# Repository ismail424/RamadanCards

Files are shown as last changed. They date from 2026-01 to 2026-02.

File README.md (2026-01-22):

# Digital Ramadan Cards Project

**By Ismail Sacic**

Welcome to the Digital Ramadan Cards project! This repository contains the design and source files for creating unique, digital printed circuit board (PCB) cards specifically designed for Ramadan.

## Project Overview

I am creating digital Ramadan cards that combine traditional aesthetics with modern electronics. These cards are designed using KiCad and can be manufactured as PCBs. They serve as beautiful, tech-inspired gifts or decorative pieces to celebrate the holy month of Ramadan.

### Features
- **Design Year**: 2026
- **Format**: KiCad PCB Design
- **Custom Graphics**: Includes custom silk screen art (Mosque/Stars).

## Preview

Here are some preview images of the 2026 card design:

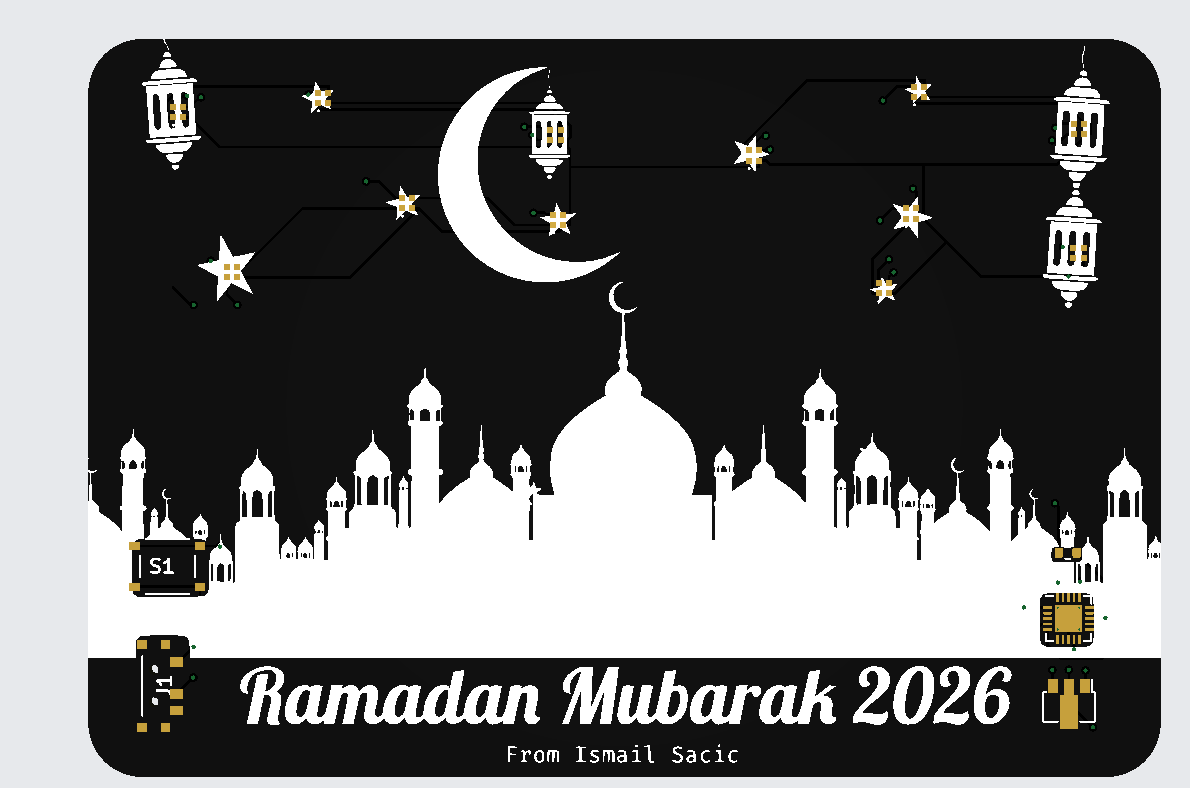
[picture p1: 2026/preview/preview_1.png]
Card Preview 1

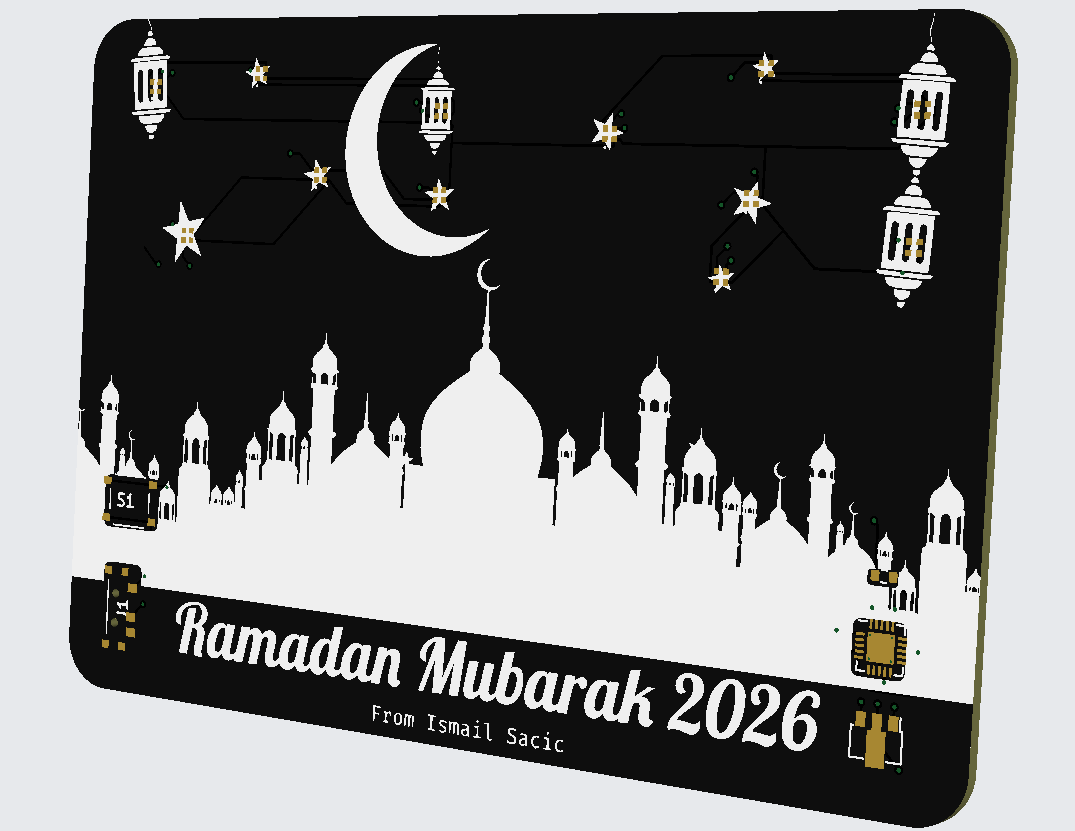
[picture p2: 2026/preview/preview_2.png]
Card Preview 2

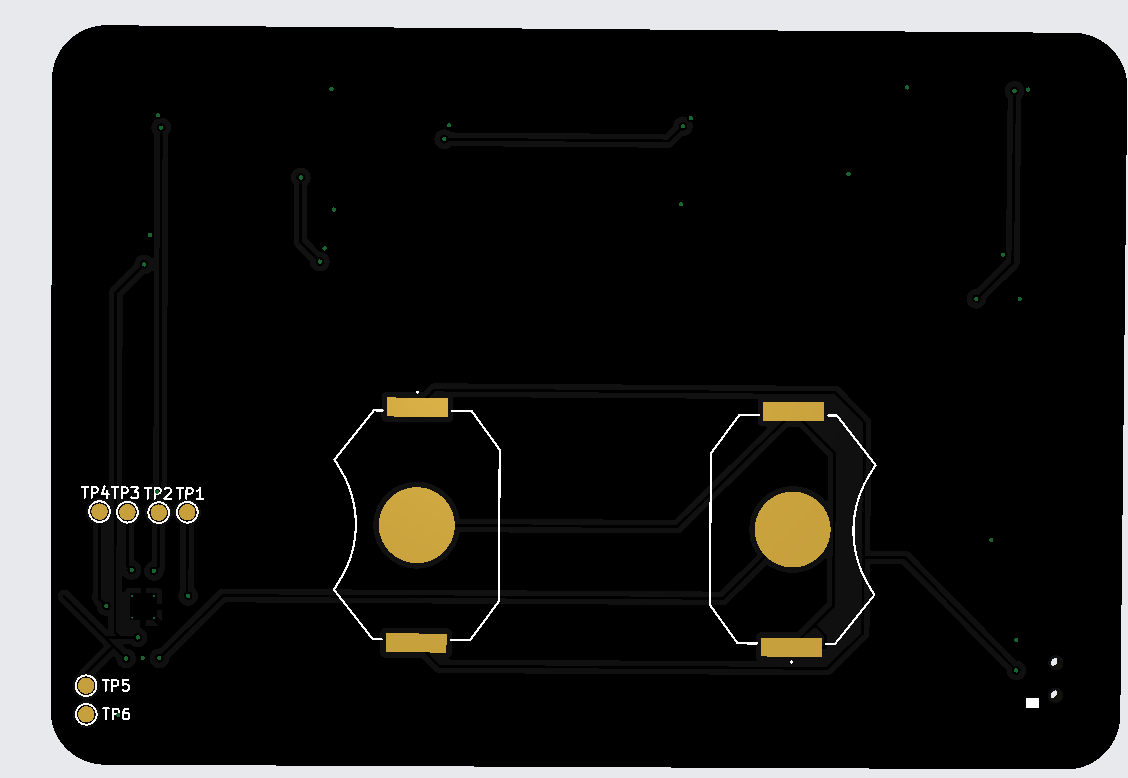
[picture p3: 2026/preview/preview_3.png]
Card Preview 3


## Repository Structure

- `2026/` : Contains the KiCad project files for the 2026 edition.
  - `gr/` : Gerber files for manufacturing.
  - `Graphics/` : Custom footprints and graphics used on the PCB.
  - `preview/` : Images of the design.

## How to Open

1. Install [KiCad](https://www.kicad.org/).
2. Open the `.kicad_pro` file located in the `2026/` directory.

## License

**Copyright © 2026 Ismail Sacic. All Rights Reserved.**

This project is for personal viewing only. **You are not allowed to manufacture, produce, or sell** cards based on this design. See the [LICENSE](LICENSE) file for more details.

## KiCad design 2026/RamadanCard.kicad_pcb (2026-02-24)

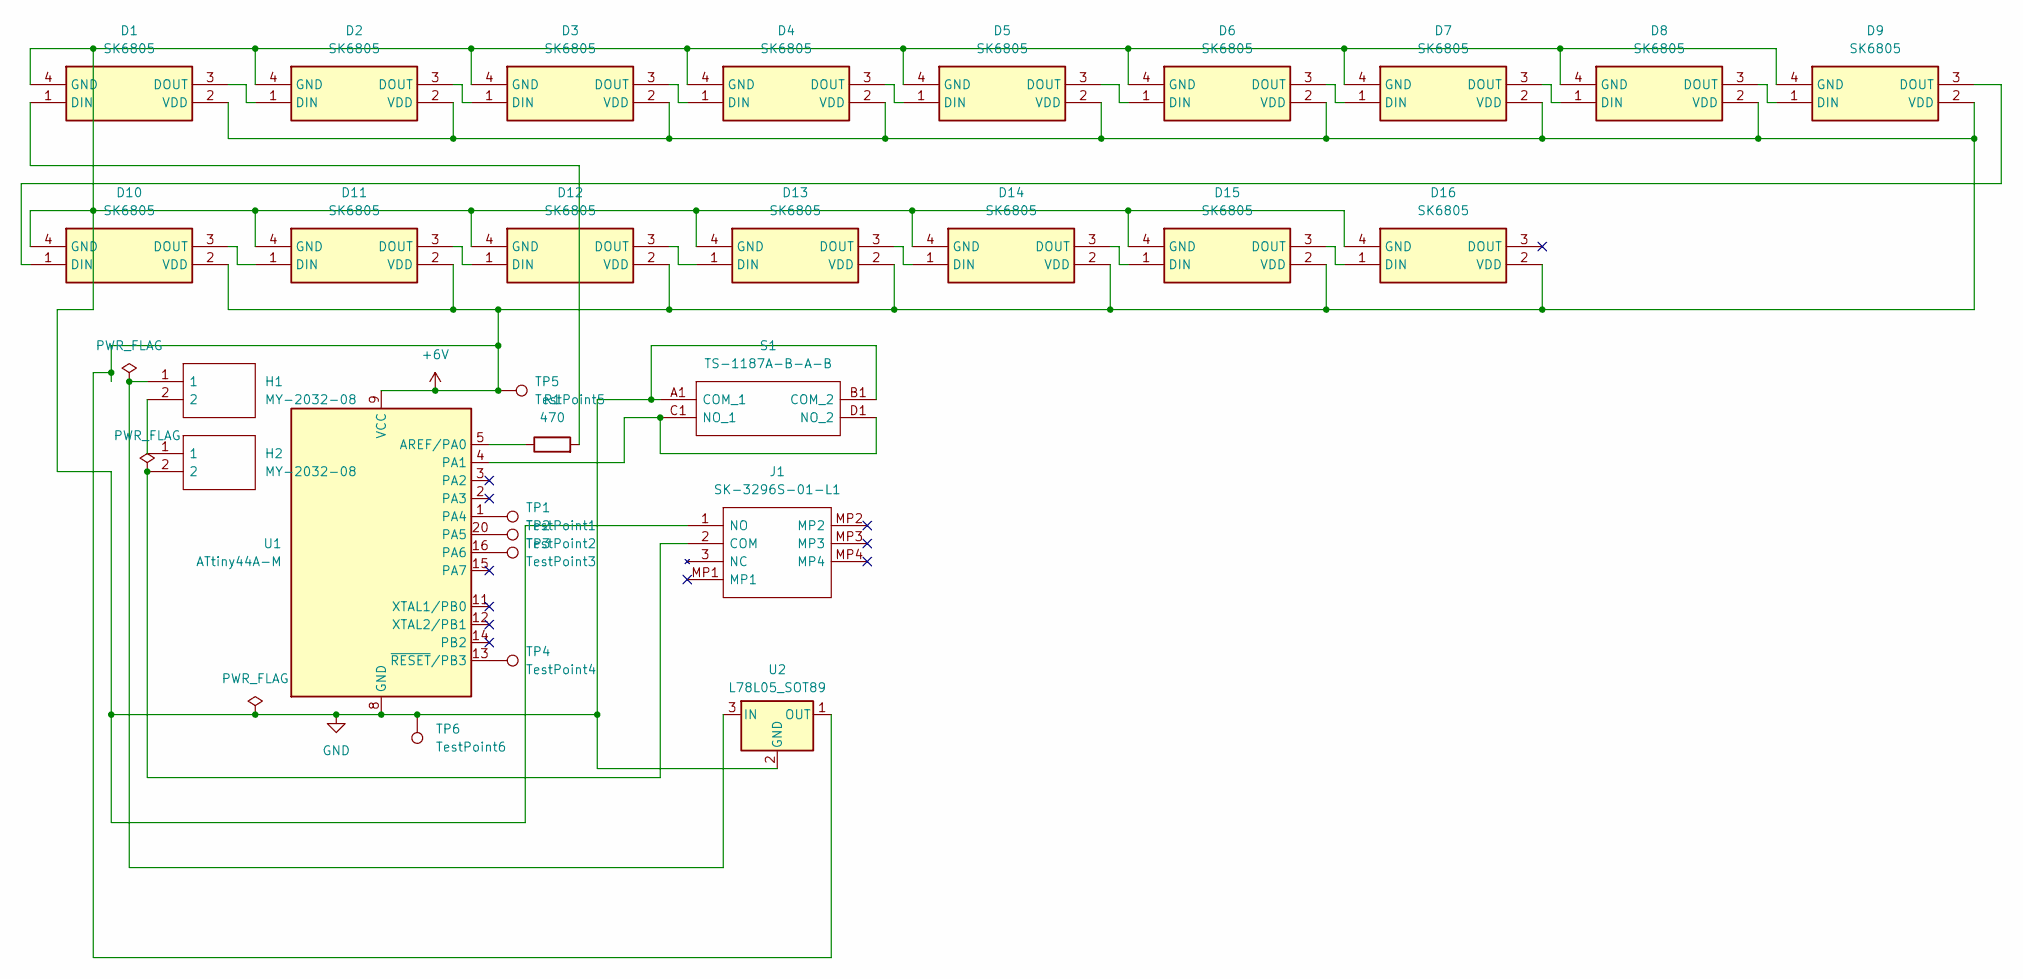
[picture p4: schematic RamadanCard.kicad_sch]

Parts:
D1, D2, D3, D4, D5, D6, D7, D8, D9, D10, D11, D12, D13, D14, D15, D16: SK6805; LED_SK6812_EC15_1.5x1.5mm; Manufacturer_Part_Number SK6805-EC15
H1, H2: MY-2032-08; MY203208; Manufacturer_Part_Number MY-2032-08
J1: SK-3296S-01-L1; SK3296S01L1; Manufacturer_Part_Number SK-3296S-01-L1
R1: 470; R_0603_1608Metric
S1: TS-1187A-B-A-B; TS1187ABAB; Manufacturer_Part_Number TS-1187A-B-A-B
TP1: TestPoint1; TestPoint_Pad_D1.5mm
TP2: TestPoint2; TestPoint_Pad_D1.5mm
TP3: TestPoint3; TestPoint_Pad_D1.5mm
TP4: TestPoint4; TestPoint_Pad_D1.5mm
TP5: TestPoint5; TestPoint_Pad_D1.5mm
TP6: TestPoint6; TestPoint_Pad_D1.5mm
U1: ATtiny44A-M; QFN-20-1EP_4x4mm_P0.5mm_EP2.5x2.5mm_ThermalVias
U2: L78L05_SOT89; SOT-89-3

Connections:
+6V: D1.2 (VDD), D2.2 (VDD), D3.2 (VDD), D4.2 (VDD), D5.2 (VDD), D6.2 (VDD), D7.2 (VDD), D8.2 (VDD), D9.2 (VDD), D10.2 (VDD), D11.2 (VDD), D12.2 (VDD), D13.2 (VDD), D14.2 (VDD), D15.2 (VDD), D16.2 (VDD), TP5.1, U1.9 (VCC), U2.1 (OUT)
GND: D1.4 (GND), D2.4 (GND), D3.4 (GND), D4.4 (GND), D5.4 (GND), D6.4 (GND), D7.4 (GND), D8.4 (GND), D9.4 (GND), D10.4 (GND), D11.4 (GND), D12.4 (GND), D13.4 (GND), D14.4 (GND), D15.4 (GND), D16.4 (GND), J1.1 (NO), S1.A1 (COM_1), S1.B1 (COM_2), TP6.1, U1.8 (GND), U1.21 (GND), U2.2 (GND)
unnamed: D1.1 (DIN), R1.2
unnamed: D1.3 (DOUT), D2.1 (DIN)
unnamed: D2.3 (DOUT), D3.1 (DIN)
unnamed: D3.3 (DOUT), D4.1 (DIN)
unnamed: D4.3 (DOUT), D5.1 (DIN)
unnamed: D5.3 (DOUT), D6.1 (DIN)
unnamed: D6.3 (DOUT), D7.1 (DIN)
unnamed: D7.3 (DOUT), D8.1 (DIN)
unnamed: D8.3 (DOUT), D9.1 (DIN)
unnamed: D9.3 (DOUT), D10.1 (DIN)
unnamed: D10.3 (DOUT), D11.1 (DIN)
unnamed: D11.3 (DOUT), D12.1 (DIN)
unnamed: D12.3 (DOUT), D13.1 (DIN)
unnamed: D13.3 (DOUT), D14.1 (DIN)
unnamed: D14.3 (DOUT), D15.1 (DIN)
unnamed: D15.3 (DOUT), D16.1 (DIN)
unnamed: H1.2, H2.1
unnamed: H2.2, J1.2 (COM)
unnamed: S1.C1 (NO_1), S1.D1 (NO_2), U1.4 (PA1)
unnamed: R1.1, U1.5 (AREF/PA0)
unnamed: TP1.1, U1.1 (PA4)
unnamed: TP2.1, U1.20 (PA5)
unnamed: TP3.1, U1.16 (PA6)
unnamed: TP4.1, U1.13 (~RESET/PB3)
unnamed: H1.1, U2.3 (IN)

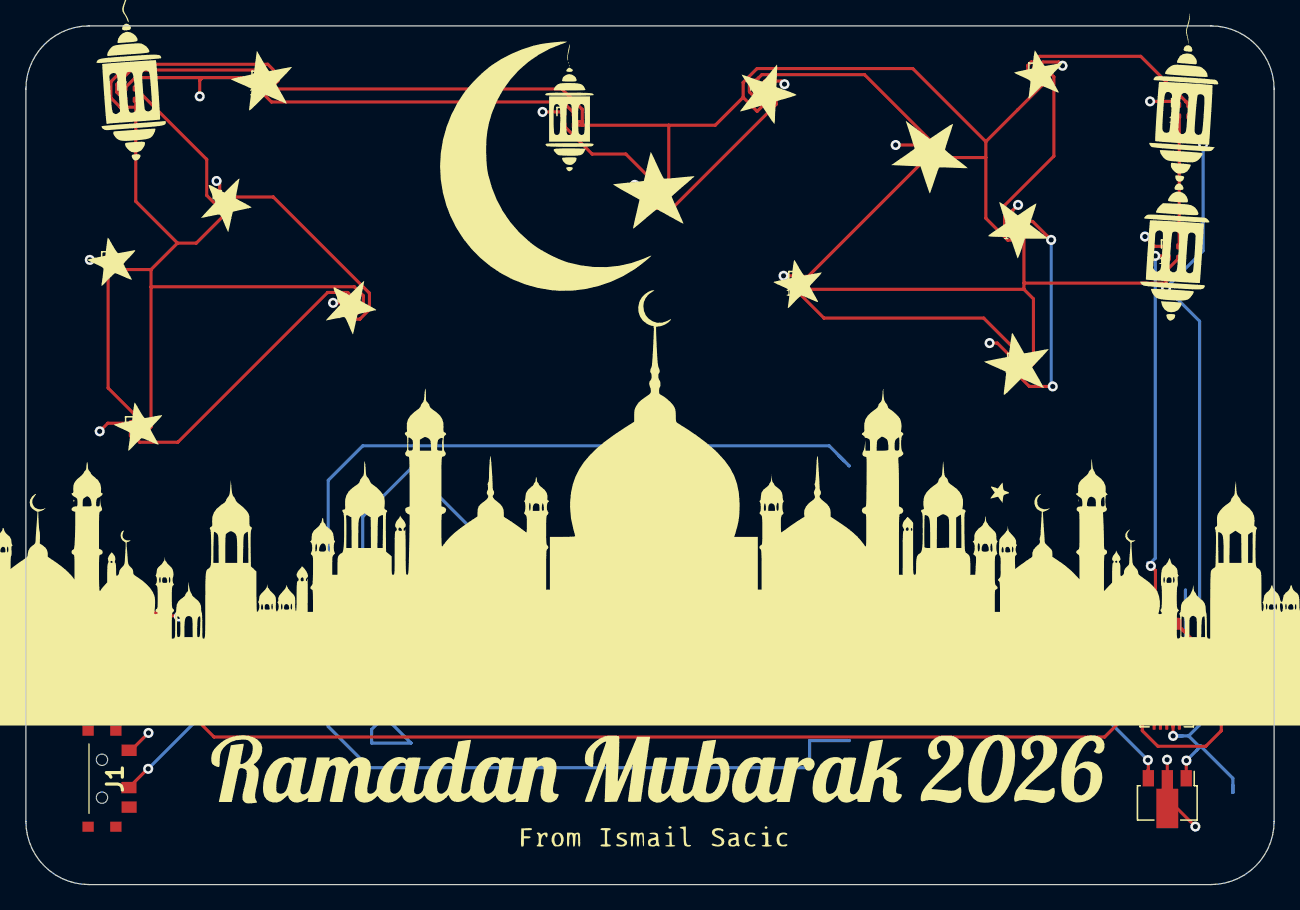
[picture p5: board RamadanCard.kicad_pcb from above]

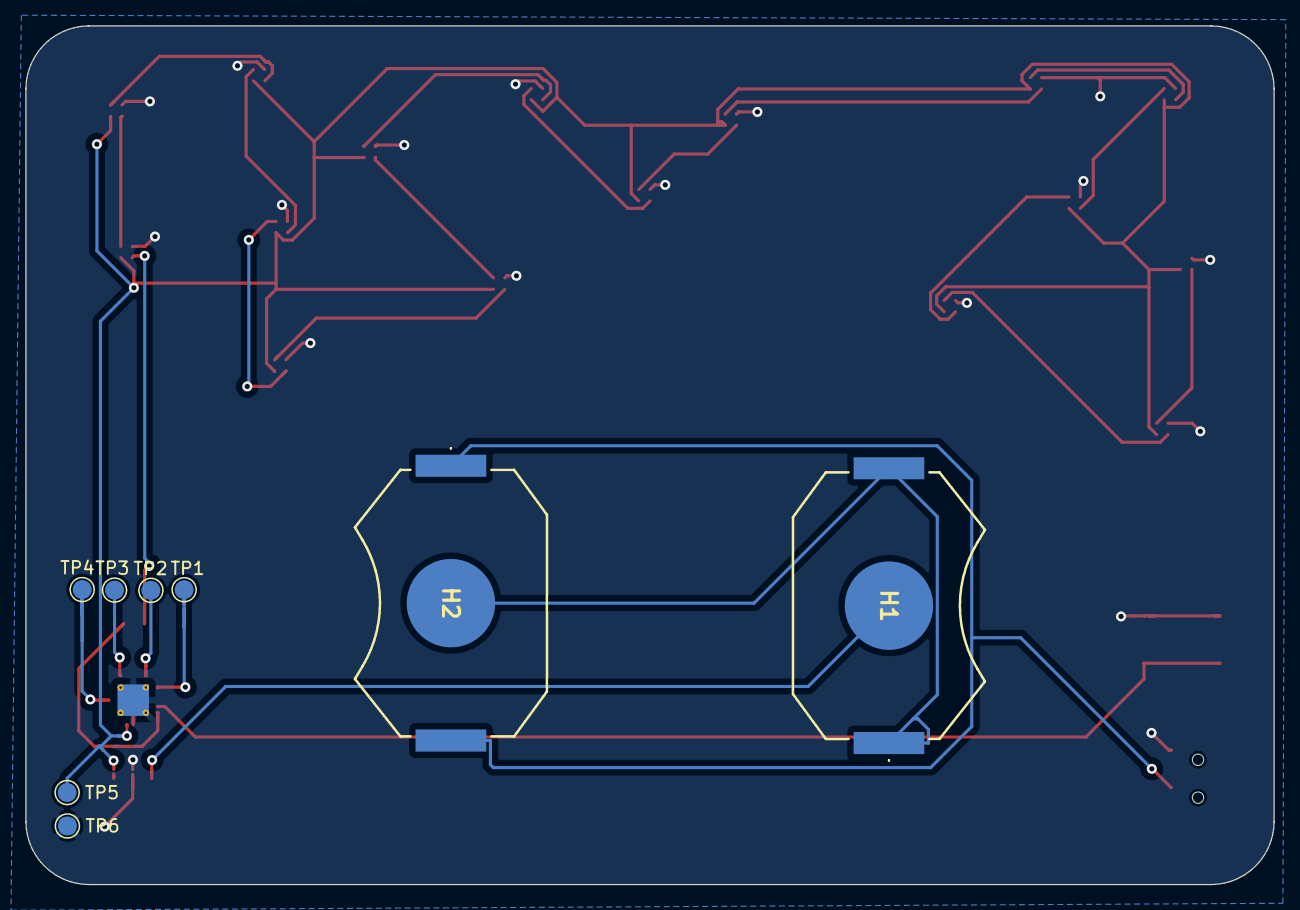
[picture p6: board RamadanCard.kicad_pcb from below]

Board: 2 copper layers, 98.8 x 68.0 mm, 29 parts (8 on the bottom side), 27 nets.

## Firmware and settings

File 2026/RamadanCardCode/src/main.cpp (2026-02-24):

#include <Arduino.h>
#include <FastLED.h>

#define LED_PIN     0
#define COLOR_ORDER GRB
#define CHIPSET     WS2812B
#define NUM_LEDS    16
#define BRIGHTNESS  100
#define BUTTON_PIN  9
#define HOLD_MS     400
#define CLICK_GAP   350

CRGB leds[NUM_LEDS];

uint8_t mode = 0;
uint8_t clickCount = 0;
bool lastBtn = false;
bool holding = false;
unsigned long pressTime = 0;
unsigned long releaseTime = 0;
uint8_t seq0 = 0, seq1 = 0, seq2 = 0;

void twinkle() {
  fadeToBlackBy(leds, NUM_LEDS, 20);
  if (random8() < 80)
    leds[random8(NUM_LEDS)] = CRGB(255, 180, 50);
}

void breathe() {
  uint8_t t = millis() >> 3;
  uint8_t v = (t < 128) ? t * 2 : (255 - t) * 2;
  fill_solid(leds, NUM_LEDS, CRGB(v, v >> 1, 0));
}

void rainbow() {
  fill_rainbow(leds, NUM_LEDS, millis() / 20, 28);
}

// 424 easter egg: lights up 4, 2, 4 stars one by one
void show424() {
  fill_solid(leds, NUM_LEDS, CRGB::Black);
  uint8_t p = 0;
  for (uint8_t d = 0; d < 3; d++) {
    for (uint8_t i = 0; i < ((d == 1) ? 2 : 4); i++) {
      leds[p++] = CRGB(255, 180, 50);
      FastLED.show(); delay(200);
    }
    delay(500);
  }
}

void setup() {
  delay(500);
  pinMode(BUTTON_PIN, INPUT_PULLUP);
  FastLED.addLeds<CHIPSET, LED_PIN, COLOR_ORDER>(leds, NUM_LEDS);
  FastLED.setBrightness(BRIGHTNESS);
}

void loop() {
  bool btn = (digitalRead(BUTTON_PIN) == LOW);
  unsigned long now = millis();

  if (btn && !lastBtn) { pressTime = now; holding = false; }
  if (btn && !holding && (now - pressTime > HOLD_MS)) { holding = true; clickCount = 0; }
  if (!btn && lastBtn) {
    if (!holding) { clickCount++; releaseTime = now; }
    holding = false;
  }
  if (clickCount > 0 && !btn && (now - releaseTime > CLICK_GAP)) {
    seq0 = seq1; seq1 = seq2; seq2 = clickCount;
    if (seq0 == 4 && seq1 == 2 && seq2 == 4) {
      show424(); mode = 0; seq0 = seq1 = seq2 = 0;
    } else if (clickCount >= 3) mode = 3;
    else if (clickCount == 2) mode = 2;
    else mode = (mode == 0) ? 1 : 0;
    clickCount = 0;
  }

  if (btn && holding) rainbow();
  else if (mode == 1) twinkle();
  else if (mode == 2) breathe();
  else if (mode == 3) rainbow();
  else fill_solid(leds, NUM_LEDS, CRGB::Black);

  FastLED.show();
  delay(16);
  lastBtn = btn;
}
